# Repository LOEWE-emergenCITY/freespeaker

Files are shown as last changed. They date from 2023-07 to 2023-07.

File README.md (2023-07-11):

# FreeSpeaker

This repository provides the current state of our modular smart speaker research platform called **FreeSpeaker**.

### :warning: Work in progress
The current state of the FreeSpeaker is a first beta version.
We plan to update the design and add changes that will lead to incompatibilities with current hardware.

## Mechanical design
[][cc-by]

Find the CAD files for the plattform in `mechanical_design/`.
The components were designed to be 3D printed.

Tools: Autodesk Fusion 360 or any CAD program compatible with STEP files.

The CAD files are licensed under a [Creative Commons Attribution 4.0 International License][cc-by].

## PCB design
[][cc-by]
Find the design files for the PCB in `electric_design/`.

Tools: KiCad 6.x

The electrical design files are licensed under a [Creative Commons Attribution 4.0 International License][cc-by].

## Software 
[][mit]
Find scripts to setup the different components in `software/`.

The software components are licensed under a [MIT License][mit].

---

The following demo paper was send to review at [MobiCom 2023](https://www.sigmobile.org/mobicom/2023/demos.html).

---

## Demo: Introducing FreeSpeaker -- A Modular Smart Home Hub Prototyping Platform
Smart home speakers have become a commodity item in many households and provide interesting research opportunities in areas like wireless communication and human-computer interaction.
Commercial devices do not provide sufficient access for many research tasks.
We present a modular smart home hub designed specifically for research purposes.
The electronic and mechanical components are designed with reproducibility in mind and can be easily recombined for a project's needs.
Additionally, we show applications of the hub in different scenarios.
  
### Introduction

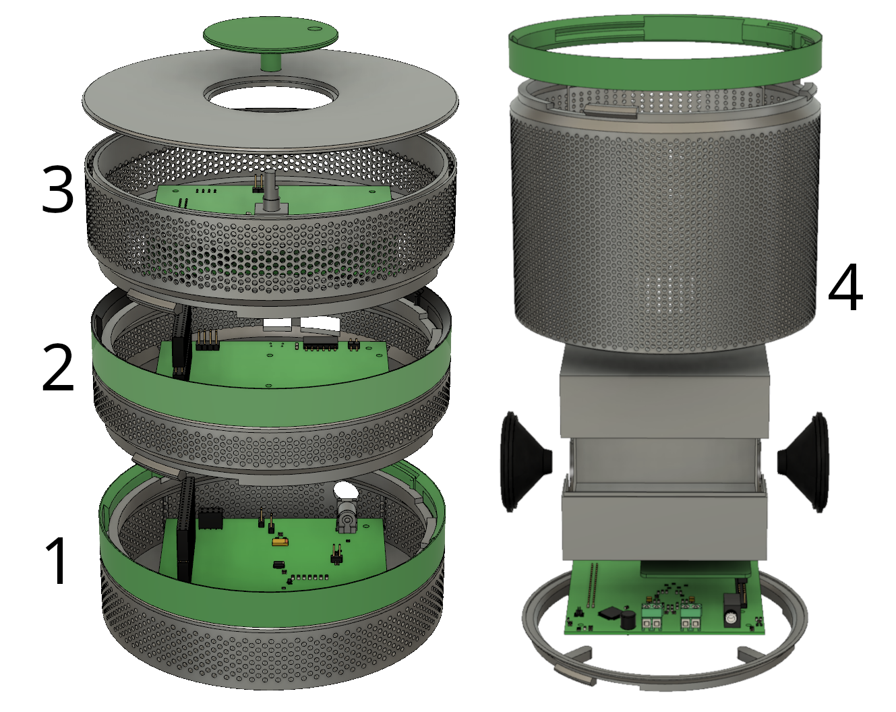
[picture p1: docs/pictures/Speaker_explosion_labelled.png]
FreeSpeaker exploded view


Exploded view: On the left a stack of power supply (1), mainboard (2), and on top the UI (3). On the right (4), separately and in greater detail, the module with the speaker drivers for audio output.

Smart home speakers like Amazon Alexa or Google Nest have become increasingly popular in the last years.
This sparks interest to use them for investigating topics such as acoustic communication, evaluating new wireless communication schemes, or studying novel human-computer-interaction patterns
\[ [1](https://doi.org/10.1109/INFOCOM.2015.7218629),
[2](https://doi.org/10.1109/TMM.2017.2766049),
[3](https://doi.org/10.1109/MPRV.2003.1228528),
[4](https://doi.org/10.1145/2462456.2464437),
[5](https://doi.org/10.1007/978-3-540-39653-6_25) \].
While commercial speakers are cheap and readily available for consumers, their closed nature does not provide a suitable platform for research.
Neither their hardware nor software documentation is publicly available and researchers cannot run arbitrary experiments on them.
Some attempts to reverse engineer commercial smart speakers have been successful
[6](https://andrerh.gitlab.io/echoroot/) but a fully open hardware platform would still benefit the research community.
Additionally, features not available in commercial devices like special radio protocols can be implemented, if needed.
A modular system helps with this, as new functionality can be added easily.

In this demo, we show such a modular platform called FreeSpeaker based on a Raspberry Pi Compute Module 4 (CM4).
We designed and built the electronics for this system including the basic modules implementing the functionality of modern smart speakers.
We publish the current state of the design files for electronics and mechanical parts as well as scripts for setting up the system on GitHub. (this repo)

### Design
Different components to run the smart home hub are split into modules that can be reassembled without any tools.
So far we implemented a power supply module, the mainboard containing the CM4, a speaker and microphone array combination, and a user interface with LEDs and a rotary encoder.
Additionally, we provide a prototyping module with a small breadboard on top.
Reproducibility of the hardware was a main concern to enable other researchers to build their own hardware.
Therefore, the electronics are designed to be easily produced and assembled by major PCB prototyping companies, need only minor additional work and no special tools other than soldering equipment.
The enclosure is designed for 3D printing since it provides a cheap way to produce low volumes of plastic parts.

#### Electronic Design
During PCB development, we ensured that boards can be manufactured with easily accessible soldering tools.
Each signal is accessible via test pads and soldering bridges to enable changes on the PCB without reordering.
The main controller module is a [CM4](https://www.raspberrypi.com/products/compute-module-4/) that provides CPU, RAM, and storage available in different configurations.
The mainboard supports a serial console and Ethernet.
We used the same connector on all modules to provide power and to allow communication between the modules and the mainboard.
Each module connects to a bus that enables hardware identification and in-circuit firmware updates.

#### Mechanical Design
Each module of the hub has a round, stackable enclosure.
We designed a tool-free mechanism with a lock ring to hold the modules together.
Additionally, the mechanism aligns the modules' electrical contacts and ensures their correct orientation.

#### Software Design
We chose the CM4 to benefit from the large and well-maintained software repositories of the Raspberry Pi ecosystem.
We provide an install script that sets Linux Device Tree parameters and installs required drivers to use the custom hardware setup.
Then, researchers can install additional packages as required by their project.

### Applications
Our hardware platform enables researchers to build proofs of concept.
During first demonstrations, participants easily recognized the device as a Smart Speaker.
This allows researchers to focus on the new application rather than explaining the intended environment.
The following sections give a short overview of running projects using the device.

#### Public Warning Systems in Smart Homes
In the living lab [*eHUB*](https://www.emergencity.de/missions/ehub/), the FreeSpeaker is integrated into the smart home setup.
Our device is one of multiple actors in the house which all connect to a local MQTT broker.
The UI of the FreeSpeaker is available to the main controller of the house and enables inhabitants or guests to control the smart home system.
Currently, we use the speaker and an electronic paper display in the eHUB in combination to provide visual and audible information.

#### Secure Bootstrapping Using Acoustic Communication
Scheck et al. [7](https://doi.org/10.26083/tuprints-00024180) used the FreeSpeaker to implement a secure pairing process with an acoustic out-of-band channel.
While commercially available smart speakers theoretically provide the required hardware for acoustic pairing, software access to them is too restricted.
The FreeSpeaker enabled them to demonstrate their protocol on a device similar to available smart speakers.

### Future Work
We demonstrated the general viability of our smart speaker as a research platform with a flexible mechanical design and modular swappable components, while still being easy to assemble.
Based on our experience with the first platform revision, we plan to redesign the PCB and signal routing to support future extensions of our platform with improved modules for battery, display, and wireless protocols.
This PCB redesign will result in incompatibilities, whereas our mechanical design remains compatible.

---
This work has been funded by the LOEWE initiative (Hesse, Germany) within the emergenCITY center.

[cc-by]: https://creativecommons.org/licenses/by/4.0/
[cc-by-shield]: https://img.shields.io/badge/License-CC%20BY%204.0-lightgrey.svg
[mit-shield]: https://img.shields.io/badge/License-MIT-lightgrey.svg
[mit]: https://opensource.org/license/mit/

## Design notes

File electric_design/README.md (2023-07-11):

# Electronic
This subfolder is used for the circuit and PCB Design.

For developing we used KiCAD which is an open source CAD software.
It was used by the Raspberry Pi Foundation for their IO Board and the Compute Module.

## Project Structure
The next block shows the structure of files used from KiCAD.

ONLY store files we already build.
First step will only have project and schematics!
```
├── FreeSpeaker-backups
│   ├── [..] KiCAD Auto save files
├── FreeSpeaker.csv (generated bill of material)
├── FreeSpeaker.kicad_pcb (pcb design )
├── FreeSpeaker.kicad_prl (pcb design )
├── FreeSpeaker.kicad_pro (kicad project file)
├── FreeSpeaker.kicad_sch (kicad schematic)
├── hardwareID_connector
│   ├── hardwareID_connector.kicad_pro
│   └── hardwareID_connector.kicad_sch
├── LoRaWan
│   ├── LoRaWan.kicad_pro
│   └── LoRaWan.kicad_sch
├── Mainboard
│   ├── Mainboard.kicad_pro
│   └── Mainboard.kicad_sch
├── PowerSupply
│   ├── PowerSupply.kicad_pro
│   └── PowerSupply.kicad_sch
├── PrototypingSlice
│   ├── PrototypingSlice.kicad_pro
│   └── PrototypingSlice.kicad_sch
├── Speaker
│   ├── Speaker.kicad_pro
│   └── Speaker.kicad_sch
└── UserInterface
    ├── UserInterface.kicad_pro
    └── UserInterface.kicad_sch
```

Each subdir is a stand alone KiCAD project.

The top level project is
- for referencing the different schematics
- showing the dependencies between the different PCBs
- documentation
- generating a full bill of material

The sub project are used to build the separate PCB for the module itself.

## Libraries
KiCAD brings a set of libraries for footprints and symbols.

For this project we needed to build our own symbols.
To use these libs generate links to the lib files or fix path settings in KiCAD.
Project libs do not work as we just created multiple project using this libs.

Due to unknown licences we removed the symbols, footprints and 3D files from third parties.

## Install and Versions KiCAD
We selected this program because it was used to build the IO Baord for the compute module.
So this project serves as a good reference to start.

The Raspberry Pi foundation used the beta version which has some features needed to build the IO Board.
So we also use the beta version of KiCad v6.x.

To publish the data we checked the files with the current release (v7.0.5).

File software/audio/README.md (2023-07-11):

# Audio on Raspberry
The FreeSpeaker uses a module to run audio.

IMPORTANT: The amplifier can be disabled with a GPIO. Check GPIO 17 and enable the amplifier.

```
echo 17 > /sys/class/gpio/export
echo out >/sys/class/gpio/gpio17/direction
echo 1 >/sys/class/gpio/gpio17/value
echo 0 >/sys/class/gpio/gpio17/value
```

This readme shows how to install the drivers provides some details on pitfalls and updates.

The ReSpeaker Module is integrated to the ALSA (Advanced Linux Sound Architecture).

These two files show the default hardware configuration for ALSA on the CM4 and the updated version after installation.
- [fresh install](fresh_install.md)
- [after successfull install](ReSpeaker_hardware_alsa.md)

## Install (short version without problems)
After flashing the CM4 this commands bring the audio hardware to live.
This may break with future updates...

```
pi@raspberrypi:~ $ uname -r
5.15.56-v8+
pi@raspberrypi:~ $ git clone https://github.com/leinher/seeed-voicecard
pi@raspberrypi:~ $ cd seeed-voicecard/
pi@raspberrypi:~ $ sudo ./install_arm64.sh
[ lots of output it something does not work you need that again... ]
pi@raspberrypi:~ $ reboot

## Install Pitfalls
The install steps on the [seeed webside](https://wiki.seeedstudio.com/ReSpeaker_4-Mic_Linear_Array_Kit_for_Raspberry_Pi/) provide commands to install the software.

**WARNING:** The FreeSpeaker is based on the CM4 and uses a 64bit architecture.
To install the ReSpeaker drivers on arm64 you need to use a different install script: `./install_arm64.sh`

```
pi@raspberrypi:~ $ uname -r
5.15.56-v8+
```

```
git clone https://github.com/respeaker/seeed-voicecard.git
cd seeed-voicecard/
sudo ./install_arm64.sh
reboot
```

These commands did not work as expected. The hardware was not available after the reboot.

A closer look at the install script output showed that the kernel module could not build and was not installed.
The script does not provide any highlighted errors or warnings.

As of today, the problem is already fixed and a [pull request](https://github.com/respeaker/seeed-voicecard/pull/323) is ready to merge for the seeed team.

To run the ReSpeaker on the FreeSpeaker the gpio pinout was adjusted.
All changes to the original project are stored in a fork (currently on my private github account).

```
git remote add leinher https://github.com/leinher/seeed-voicecard
git fetch leinher
git checkout leinher:master
pi@raspberrypi:~/seeed-voicecard $ git log -n 1
commit 0b9dcad1e5e70db9ce3c5411b020ea8e39c129ff (HEAD -> master, leinher/master)
Author: Hermann Leinweber <hermann.leinweber@stud.tu-darmstadt.de>
Date:   Tue Aug 23 19:07:18 2022 +0200

    Change device tree to run on freespeaker hardware v1
    reflect upstream kernel changes
```

After applying this patch the build works and the hardware is available.

## Hardware test commands
Get sample music
```
pi@raspberrypi: $ wget  https://www2.cs.uic.edu/~i101/SoundFiles/StarWars60.wav
```

### Play from ReSpeaker
The ReSpeaker hardware only supports the `S32_LE` samples.

```
pi@raspberrypi:~/seeed-voicecard $ aplay -D "hw:CARD=seeed8micvoicec,DEV=0" ~/StarWars60.wav
Playing WAVE '/home/pi/StarWars60.wav' : Signed 16 bit Little Endian, Rate 22050 Hz, Mono
aplay: set_params:1343: Sample format non available
Available formats:
- S32_LE
```

To convert a file the ALSA plugin `plug` can be used as followed:
```
aplay -D "plughw:CARD=seeed8micvoicec,DEV=0" StarWars60.wav
```

### Record sound with the ReSpeaker
The ReSpeaker hardware has to AC108 with 4 channels each.
This platform can be used for 6 mics and sterio output.

This command read from all channels but just 4 are used.
```
arecord -Dac108 -f S32_LE -r 16000 -c 8 a.wav
```

You can copy this to a computer and use `audacity` to view and listen to the samples.

Use this to replay the recored file.

```
aplay -D ac101 a.wav
```

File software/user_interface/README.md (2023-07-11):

# Hardware test user interface

## Rotary encoder (with device tree overlay)
The encoder will present itself as a input device.

The settings from the current setup in `freespeaker_setup.sh` can be checked with the `evtest` tool.

```
sudo -i
apt install evtest
evtest /dev/input/event1
evtest /dev/input/event0
```

`evtest` will show details of the accessed device and if events occur.

The overlay and linux kernel driver works far better than the rotary encoder in user space!

## Rotary encoder (without device tree overlay)
This scirpt can be used to test the rotary encoder hardware.

The script does not work very well.
Detecting right turns seems a bit difficult.

Move slowly...

Install dependencies for RPi pip files
```
sudo apt install python3-venv
sudo apt install python3-dev
```

Install python dependencies without messing with the system
```
python3 -m venv venv-encoder
. venv-encoder/bin/activate
```

Run the tests

```
python encoder.py
```

The script counts a number depending on the steps to each direction and prints multiple lines with `BUTTON` when the button is pressed.

## LEDs
The WS2812 LED ring is directly connected to the atmega on the user interface PCB.

Controlling the WS2812 from the CM4 with existing drivers is not possible.
Existing drivers (e.g. [rpi_ws281x](https://github.com/jgarff/rpi_ws281x)) use PWM or SPI hardware which are not supported by GPIO8 that we connected in our design.

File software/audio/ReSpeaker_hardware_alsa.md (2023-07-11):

pi@raspberrypi:~ $ aplay -l
**** List of PLAYBACK Hardware Devices ****
card 0: Headphones [bcm2835 Headphones], device 0: bcm2835 Headphones [bcm2835 Headphones]
  Subdevices: 8/8
  Subdevice #0: subdevice #0
  Subdevice #1: subdevice #1
  Subdevice #2: subdevice #2
  Subdevice #3: subdevice #3
  Subdevice #4: subdevice #4
  Subdevice #5: subdevice #5
  Subdevice #6: subdevice #6
  Subdevice #7: subdevice #7
card 1: seeed8micvoicec [seeed-8mic-voicecard], device 0: bcm2835-i2s-ac10x-codec0 ac10x-codec0-0 [bcm2835-i2s-ac10x-codec0 ac10x-codec0-0]
  Subdevices: 1/1
  Subdevice #0: subdevice #0
pi@raspberrypi:~ $ aplay -L
null
    Discard all samples (playback) or generate zero samples (capture)
lavrate
    Rate Converter Plugin Using Libav/FFmpeg Library
samplerate
    Rate Converter Plugin Using Samplerate Library
speexrate
    Rate Converter Plugin Using Speex Resampler
jack
    JACK Audio Connection Kit
oss
    Open Sound System
pulse
    PulseAudio Sound Server
upmix
    Plugin for channel upmix (4,6,8)
vdownmix
    Plugin for channel downmix (stereo) with a simple spacialization
default
ac108
dmixer
ac101
hw:CARD=Headphones,DEV=0
    bcm2835 Headphones, bcm2835 Headphones
    Direct hardware device without any conversions
plughw:CARD=Headphones,DEV=0
    bcm2835 Headphones, bcm2835 Headphones
    Hardware device with all software conversions
sysdefault:CARD=Headphones
    bcm2835 Headphones, bcm2835 Headphones
    Default Audio Device
dmix:CARD=Headphones,DEV=0
    bcm2835 Headphones, bcm2835 Headphones
    Direct sample mixing device
usbstream:CARD=Headphones
    bcm2835 Headphones
    USB Stream Output
hw:CARD=seeed8micvoicec,DEV=0
    seeed-8mic-voicecard, bcm2835-i2s-ac10x-codec0 ac10x-codec0-0
    Direct hardware device without any conversions
plughw:CARD=seeed8micvoicec,DEV=0
    seeed-8mic-voicecard, bcm2835-i2s-ac10x-codec0 ac10x-codec0-0
    Hardware device with all software conversions
sysdefault:CARD=seeed8micvoicec
    seeed-8mic-voicecard, bcm2835-i2s-ac10x-codec0 ac10x-codec0-0
    Default Audio Device
dmix:CARD=seeed8micvoicec,DEV=0
    seeed-8mic-voicecard, bcm2835-i2s-ac10x-codec0 ac10x-codec0-0
    Direct sample mixing device
usbstream:CARD=seeed8micvoicec
    seeed-8mic-voicecard
    USB Stream Output
pi@raspberrypi:~ $ arecord -l
**** List of CAPTURE Hardware Devices ****
card 1: seeed8micvoicec [seeed-8mic-voicecard], device 0: bcm2835-i2s-ac10x-codec0 ac10x-codec0-0 [bcm2835-i2s-ac10x-codec0 ac10x-codec0-0]
  Subdevices: 1/1
  Subdevice #0: subdevice #0
pi@raspberrypi:~ $ arecord -L
null
    Discard all samples (playback) or generate zero samples (capture)
lavrate
    Rate Converter Plugin Using Libav/FFmpeg Library
samplerate
    Rate Converter Plugin Using Samplerate Library
speexrate
    Rate Converter Plugin Using Speex Resampler
jack
    JACK Audio Connection Kit
oss
    Open Sound System
pulse
    PulseAudio Sound Server
upmix
    Plugin for channel upmix (4,6,8)
vdownmix
    Plugin for channel downmix (stereo) with a simple spacialization
default
ac108
dmixer
ac101
usbstream:CARD=Headphones
    bcm2835 Headphones
    USB Stream Output
hw:CARD=seeed8micvoicec,DEV=0
    seeed-8mic-voicecard, bcm2835-i2s-ac10x-codec0 ac10x-codec0-0
    Direct hardware device without any conversions
plughw:CARD=seeed8micvoicec,DEV=0
    seeed-8mic-voicecard, bcm2835-i2s-ac10x-codec0 ac10x-codec0-0
    Hardware device with all software conversions
sysdefault:CARD=seeed8micvoicec
    seeed-8mic-voicecard, bcm2835-i2s-ac10x-codec0 ac10x-codec0-0
    Default Audio Device
dsnoop:CARD=seeed8micvoicec,DEV=0
    seeed-8mic-voicecard, bcm2835-i2s-ac10x-codec0 ac10x-codec0-0
    Direct sample snooping device
usbstream:CARD=seeed8micvoicec
    seeed-8mic-voicecard
    USB Stream Output

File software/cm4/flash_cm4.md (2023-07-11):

# Flash CM4 on Mainboard

See `freespeaker_setup.sh` to setup the CM4.

The script does not install all dependencies to run properly.
We assume that users at this stage can find missing packages.

The script is a tool to help remember the steps and commands.
It is not intended to run without understanding it.

The following steps will setup the FreeSpeaker.

You need to finish these steps:

1. Install tools to access the EMMC on the CM4 via usb
2. Download and flash image (Raspberry Pi OS)
3. configure headless access
4. configure the linux kernel to use the hardware setup
5. boot the CM4 for the first time

Use the scripts help for further details.
```
./freespeaker_setup.sh --help
```

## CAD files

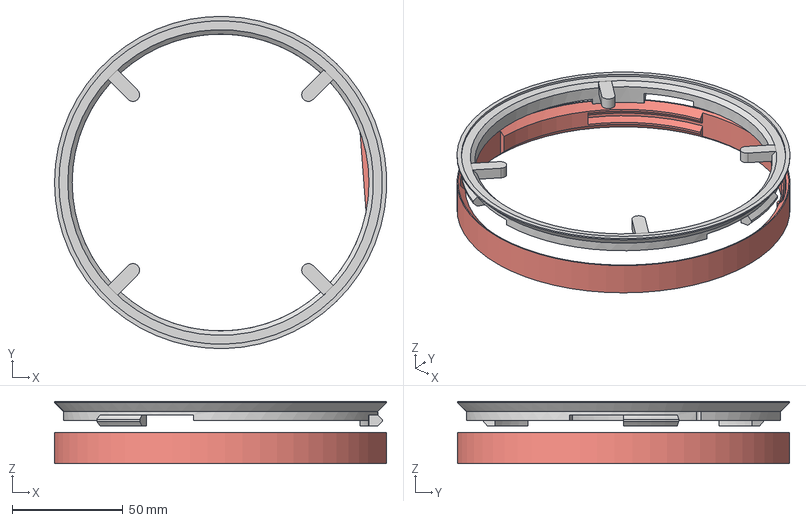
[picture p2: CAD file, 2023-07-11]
mechanical_design/step/Protyping Slice.step
149.9 x 149.9 x 28.2 mm

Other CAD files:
mechanical_design/fusion_360/Mainboard Enclosure.f3d
mechanical_design/fusion_360/Microphone_slice.f3d
mechanical_design/fusion_360/Powersupply Enclosure.f3d
mechanical_design/fusion_360/Prototyping Enclosure.f3d
mechanical_design/fusion_360/Protyping Slice.f3d
mechanical_design/fusion_360/UserInterface_Enclosure.f3d

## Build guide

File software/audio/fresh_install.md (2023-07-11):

# How did it look on a newly installed OS
pi@raspberrypi:~ $ aplay -l
**** List of PLAYBACK Hardware Devices ****
card 0: Headphones [bcm2835 Headphones], device 0: bcm2835 Headphones [bcm2835 Headphones]
  Subdevices: 8/8
  Subdevice #0: subdevice #0
  Subdevice #1: subdevice #1
  Subdevice #2: subdevice #2
  Subdevice #3: subdevice #3
  Subdevice #4: subdevice #4
  Subdevice #5: subdevice #5
  Subdevice #6: subdevice #6
  Subdevice #7: subdevice #7
card 1: vc4hdmi0 [vc4-hdmi-0], device 0: MAI PCM i2s-hifi-0 [MAI PCM i2s-hifi-0]
  Subdevices: 1/1
  Subdevice #0: subdevice #0
card 2: vc4hdmi1 [vc4-hdmi-1], device 0: MAI PCM i2s-hifi-0 [MAI PCM i2s-hifi-0]
  Subdevices: 1/1
  Subdevice #0: subdevice #0
pi@raspberrypi:~ $ aplay -L
null
    Discard all samples (playback) or generate zero samples (capture)
hw:CARD=Headphones,DEV=0
    bcm2835 Headphones, bcm2835 Headphones
    Direct hardware device without any conversions
plughw:CARD=Headphones,DEV=0
    bcm2835 Headphones, bcm2835 Headphones
    Hardware device with all software conversions
default:CARD=Headphones
    bcm2835 Headphones, bcm2835 Headphones
    Default Audio Device
sysdefault:CARD=Headphones
    bcm2835 Headphones, bcm2835 Headphones
    Default Audio Device
dmix:CARD=Headphones,DEV=0
    bcm2835 Headphones, bcm2835 Headphones
    Direct sample mixing device
hw:CARD=vc4hdmi0,DEV=0
    vc4-hdmi-0, MAI PCM i2s-hifi-0
    Direct hardware device without any conversions
plughw:CARD=vc4hdmi0,DEV=0
    vc4-hdmi-0, MAI PCM i2s-hifi-0
    Hardware device with all software conversions
default:CARD=vc4hdmi0
    vc4-hdmi-0, MAI PCM i2s-hifi-0
    Default Audio Device
sysdefault:CARD=vc4hdmi0
    vc4-hdmi-0, MAI PCM i2s-hifi-0
    Default Audio Device
hdmi:CARD=vc4hdmi0,DEV=0
    vc4-hdmi-0, MAI PCM i2s-hifi-0
    HDMI Audio Output
dmix:CARD=vc4hdmi0,DEV=0
    vc4-hdmi-0, MAI PCM i2s-hifi-0
    Direct sample mixing device
hw:CARD=vc4hdmi1,DEV=0
    vc4-hdmi-1, MAI PCM i2s-hifi-0
    Direct hardware device without any conversions
plughw:CARD=vc4hdmi1,DEV=0
    vc4-hdmi-1, MAI PCM i2s-hifi-0
    Hardware device with all software conversions
default:CARD=vc4hdmi1
    vc4-hdmi-1, MAI PCM i2s-hifi-0
    Default Audio Device
sysdefault:CARD=vc4hdmi1
    vc4-hdmi-1, MAI PCM i2s-hifi-0
    Default Audio Device
hdmi:CARD=vc4hdmi1,DEV=0
    vc4-hdmi-1, MAI PCM i2s-hifi-0
    HDMI Audio Output
dmix:CARD=vc4hdmi1,DEV=0
    vc4-hdmi-1, MAI PCM i2s-hifi-0
    Direct sample mixing device
pi@raspberrypi:~ $ arecord -l
**** List of CAPTURE Hardware Devices ****

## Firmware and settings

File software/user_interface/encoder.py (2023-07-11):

# Rotary encoder test driver

import RPi.GPIO as GPIO

def btn_pressed():
    print("BUTTON")


class Encoder(object):
    def __init__(self, A, B, T=None, Delay=None):

        GPIO.setmode(GPIO.BCM)

        self.T = T
        if T is not None:
            GPIO.setup(T, GPIO.OUT)
            GPIO.output(T,0)

        GPIO.setup(A, GPIO.IN, pull_up_down=GPIO.PUD_UP)
        GPIO.setup(B, GPIO.IN, pull_up_down=GPIO.PUD_UP)

        self.delay = Delay
        self.A = A
        self.B = B
        self.pos = 0
        self.state = (GPIO.input(B) << 1) | GPIO.input(A)
        self.edges = (0,1,-1,2,-1,0,-2,1,1,-2,0,-1,2,-1,1,0)

        if self.delay is not None:
            GPIO.add_event_detect(A, GPIO.BOTH, callback=self.__update,
                                  bouncetime=self.delay)
            GPIO.add_event_detect(B, GPIO.BOTH, callback=self.__update,
                                  bouncetime=self.delay)
        else:
            GPIO.add_event_detect(A, GPIO.BOTH, callback=self.__update)
            GPIO.add_event_detect(B, GPIO.BOTH, callback=self.__update)

    def __update(self, channel):
        if self.T is not None:
            GPIO.output(self.T,1)                   # flag entry

        state = (self.state & 0b0011)   \
            | (GPIO.input(self.B) << 3) \
            | (GPIO.input(self.A) << 2)

        gflag = '' if self.edges[state] else ' - glitch'
        if (self.T is not None) and not self.edges[state]:  # flag no-motion glitch
            GPIO.output(self.T,0)
            GPIO.output(self.T,1)

        self.pos += self.edges[state]

        self.state = state >> 2

#        print(' {} - state: {:04b} pos: {}{}'.format(channel,state,self.pos,gflag))

        if self.T is not None:
            GPIO.output(self.T,0)                   # flag exit

    def read(self):
        return self.pos

    def read_reset(self):
        rv = self.pos
        self.pos = 0
        return rv

    def write(self,pos):
        self.pos = pos
    
    if __name__ == "__main__":
        import encoder
        import time
        from gpiozero import Button

        btn = Button(22)
        enc = encoder.Encoder(23, 4,T=16)

        prev = enc.read()
        
        btn.when_pressed = btn_pressed

        while True:
        #while not btn.is_held :
            now = enc.read()
            if now != prev:
                print('{:+4d}'.format(now))
                prev = now
            if not btn.is_pressed:
                print("BUTTON")

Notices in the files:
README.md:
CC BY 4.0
